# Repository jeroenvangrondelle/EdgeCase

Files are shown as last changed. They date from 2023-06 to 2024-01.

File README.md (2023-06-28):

# Edge Case: Housing your sensors at the edge

This work is licensed under a Creative Commons Attribution-ShareAlike 4.0 International License.

## Objective

Often when developing IoT use cases, sensors and supporting boards are readily available,
but housing the electronics at the edge is a challenge.

Would it be possible to develop an easily scalable, (semi) professional case design that bridges the gap between early prototyping
and high volume deployments?

## Current version

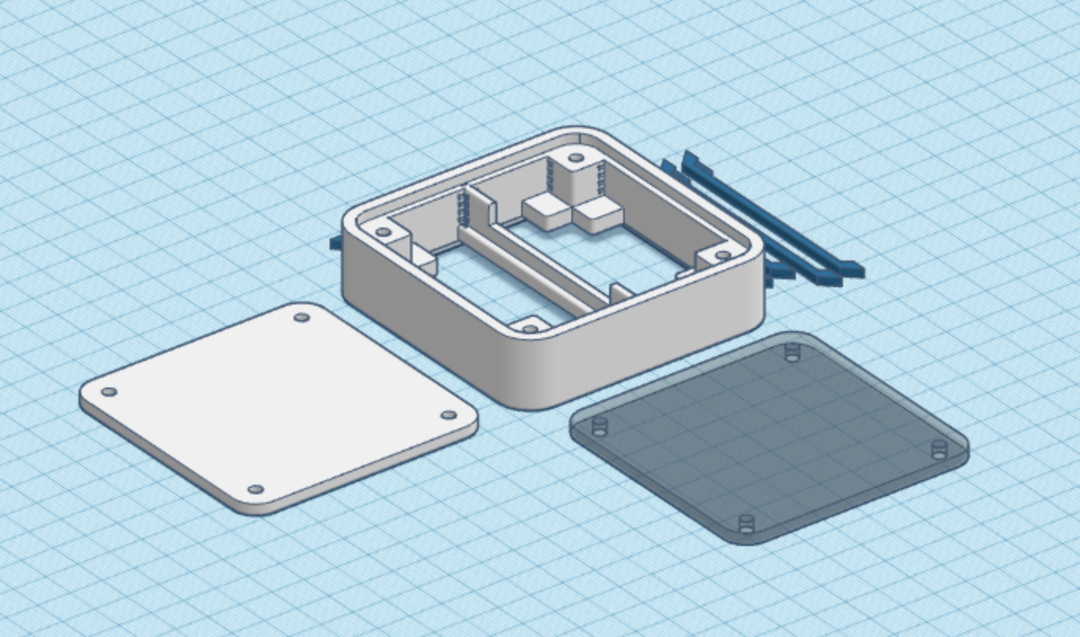
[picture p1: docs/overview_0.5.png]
Early prototype


## Features

- [ ] A base case-design with lasercut front and back and a 3D printed house
- [ ] A parametric implementation for automatic sizing to your specific PCB, battery holder, sensor, etc.
- [ ] Swappable back design: Table model, screw mounts, and DIN rail

## Scaling the case

Choose values for A, B, C and D so that your boards and/or battery holders fit, either vertically or horiontally, in the two slots.

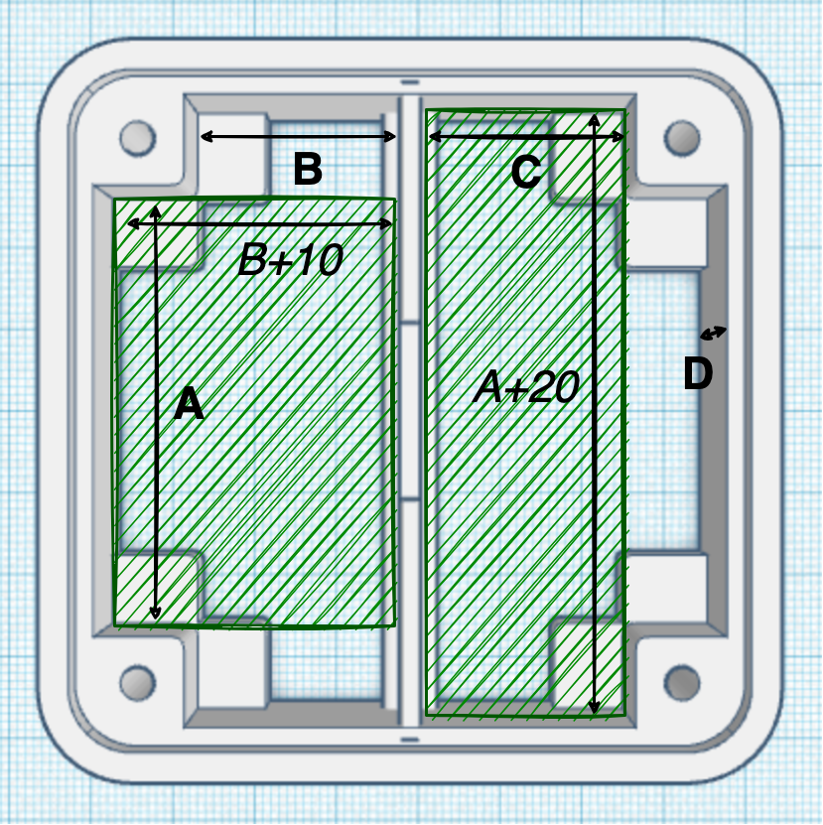
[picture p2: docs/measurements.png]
Measurements


## Roadmap for 1.0

- [ ] Connectors, (touch)buttons? 
- [ ] Status leds and ambient feedback?
- [ ] External sensor bay?
- [ ] How to parameterize the SVG's (better)?
- [ ] Online version of the design generator

## Version log

v0.2

- [X] Smoother/parallel circles
- [X] Better side thinknesses
- [X] Use screws for fixing front and back

v0.3 and v0.4

- [x] Smoother lines
- [x] Support horizontal and vertical placement
- [x] Parameterize towards PCB size + optional 2x 18650 battery holder

v0.5

- [x] Testing support for melt insert nuts (Ruthex M3 Schroefdraadbus M3 x 5.7)
- [x] Small irregularity in the design at top left corner of the case.
- [x] Fixing the boards with a clip
 
## Supported boards

| Board | A | B | C | D |
| ---|---|---|---|---|
| Firebeetle 2 (60x25.4mm, 62mm including protruding USB connector) + 18650 Battery Holder (80x21mm) | 62 mm | 16 mm | 21 mm | 30 mm |
| Arduino Nano (45x18mm) + 18650 Battery Holder (80x21mm) | 60 mm | 8 mm | 21 mm | 30 mm |

## Modding

Front and house are easy to mod. Front can be cut from plexiglas, but printing introduces extra modding options.

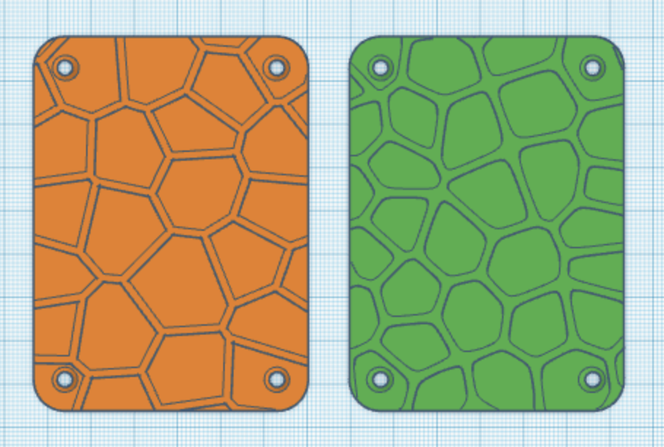
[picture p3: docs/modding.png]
Modding


## Contributors

Idea and design by Jeroen van Grondelle

With contributions and feedback from:

- Daan Boezeman
- ...

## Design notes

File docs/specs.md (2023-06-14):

In v0.2

Both bays have a size of 34x50.

Depth is 14

The board width = 47mm
- Split at 5 + 10 + slack
The bay width = 23
- Split at 5 + 47 + added + 3 + slack

The depth = 14
- Split at 10mm
The height = 50
- Split 1t 40

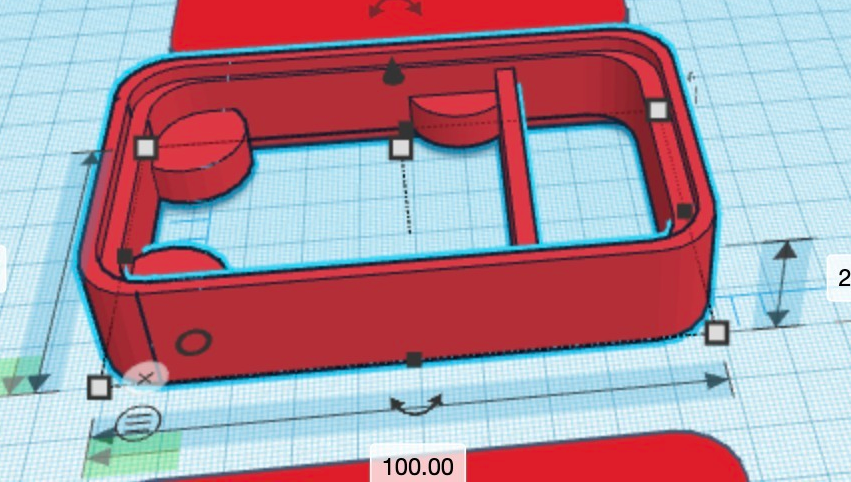
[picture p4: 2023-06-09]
docs/overview_0.1.png

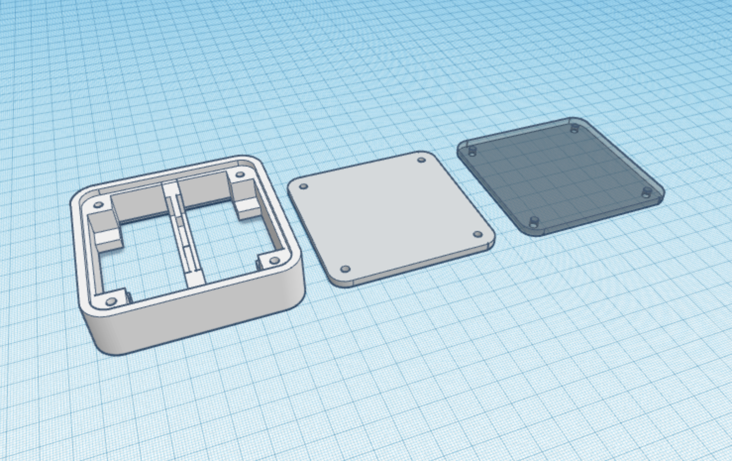
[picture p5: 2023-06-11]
docs/overview_0.2.png

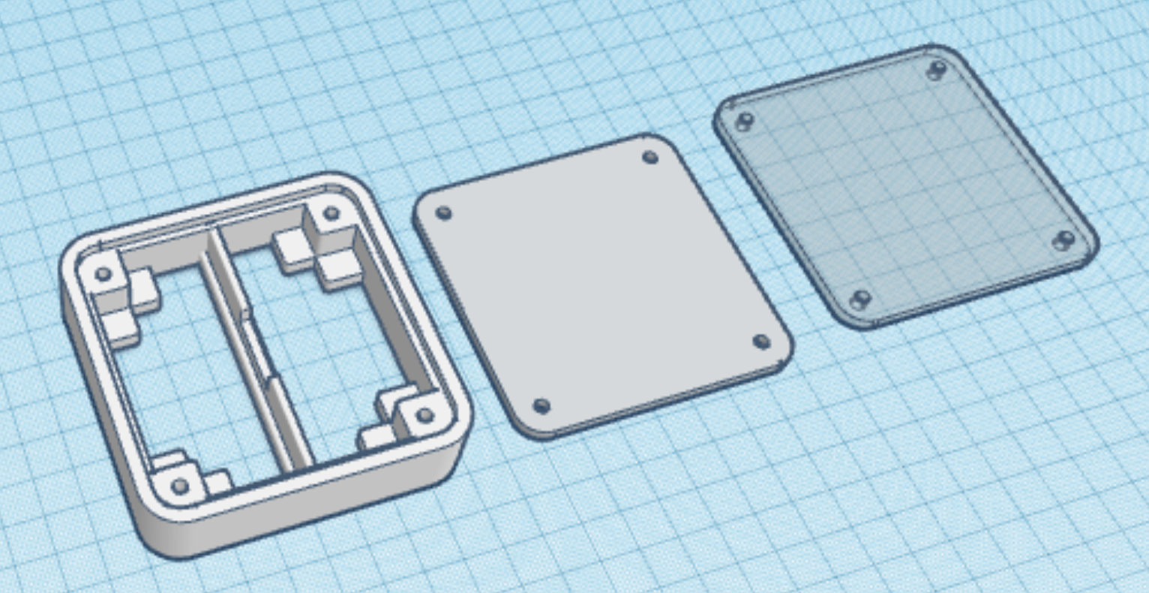
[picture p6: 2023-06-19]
docs/overview_0.4.png

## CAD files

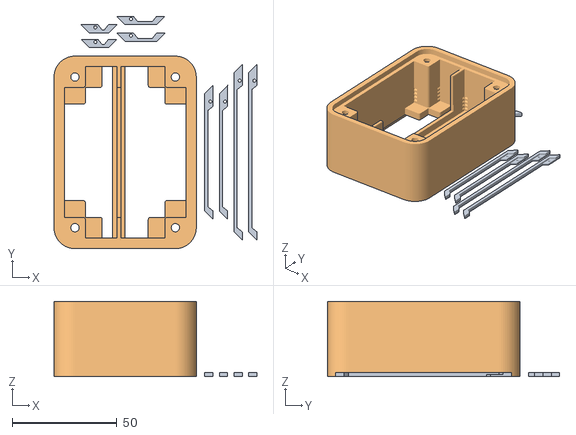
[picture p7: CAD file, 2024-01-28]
examples/liligo_18650_house.obj
97.0 x 111.0 x 36.0

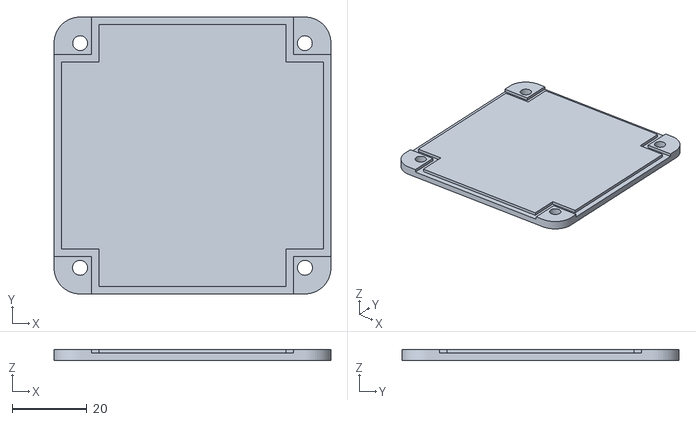
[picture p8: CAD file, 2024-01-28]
prototypes/Edge Case 0.6 WP.stl
74.0 x 74.0 x 3.00

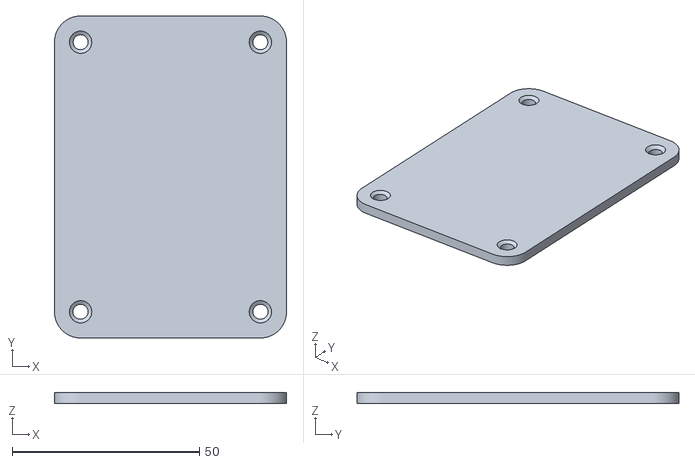
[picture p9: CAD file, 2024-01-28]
examples/liligo_18650_front.obj
62.0 x 86.0 x 3.00

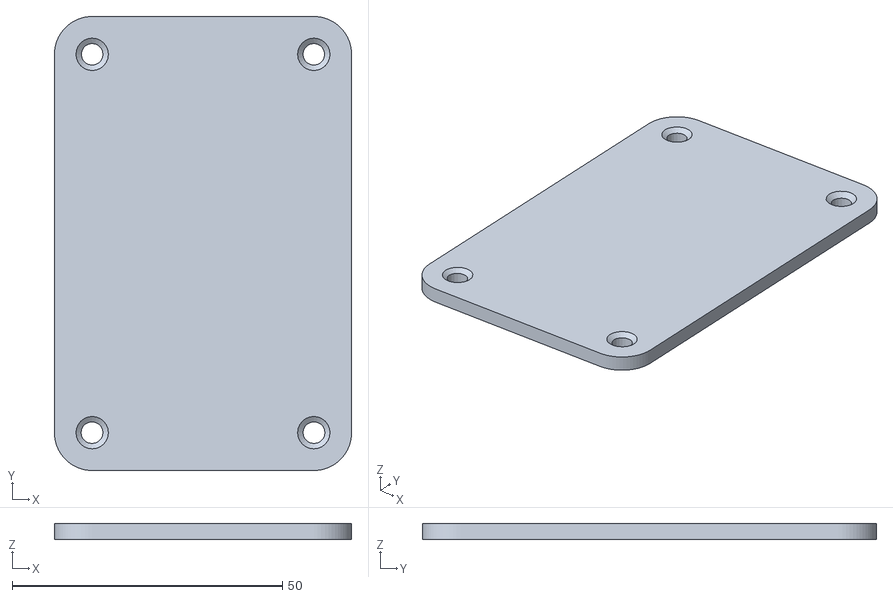
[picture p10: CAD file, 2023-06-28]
examples/nano_18650_front.obj
55.0 x 84.0 x 3.00

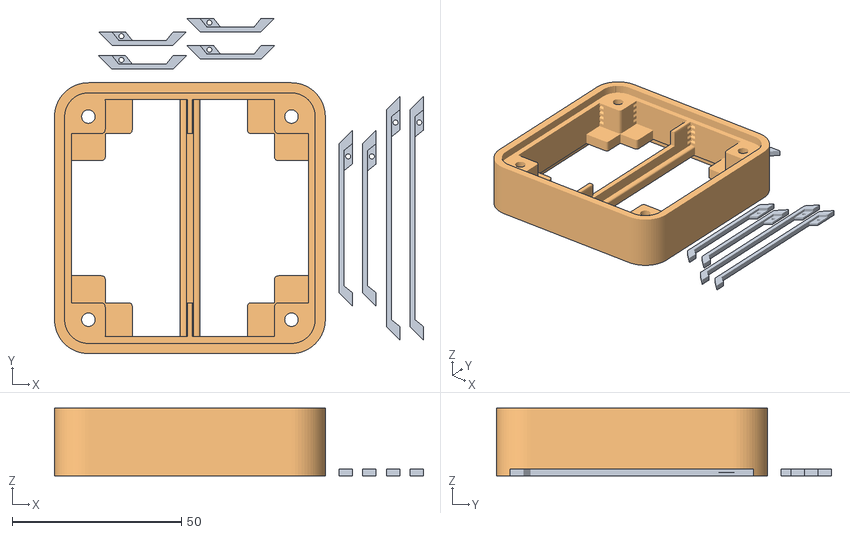
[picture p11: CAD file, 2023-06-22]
prototypes/Edge Case 0.5 House.obj
109.0 x 99.0 x 20.0

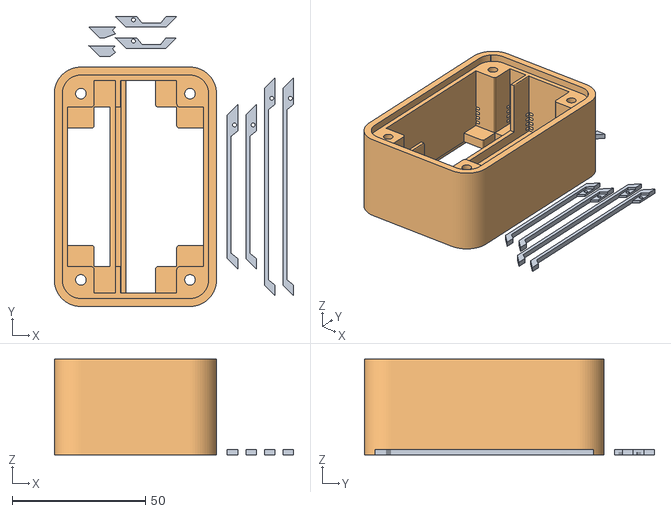
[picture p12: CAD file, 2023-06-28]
examples/nano_18650_house.obj
90.0 x 109.0 x 36.0

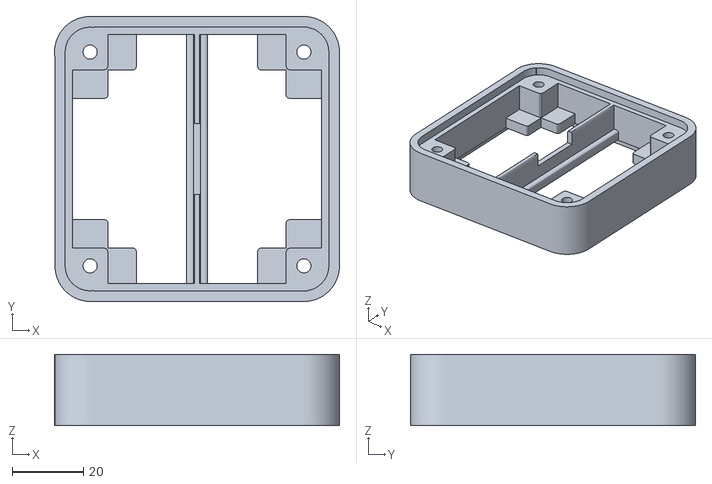
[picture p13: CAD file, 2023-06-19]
prototypes/Edge Case 0.4 House.obj
80.0 x 80.0 x 20.0

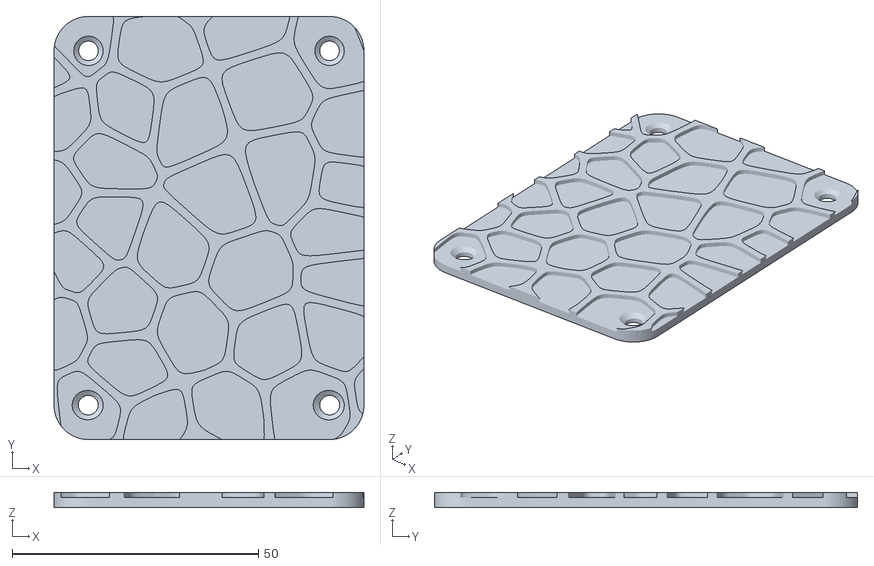
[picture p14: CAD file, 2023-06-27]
examples/single 18650_firebeetle2_front_voronoi.stl
63.0 x 86.0 x 3.00

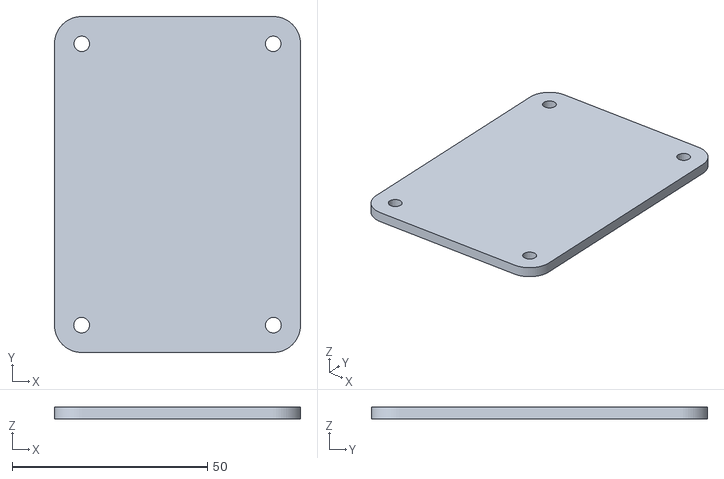
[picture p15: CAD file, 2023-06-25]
examples/single 18650_firebeetle2_front.obj
63.0 x 86.0 x 3.00

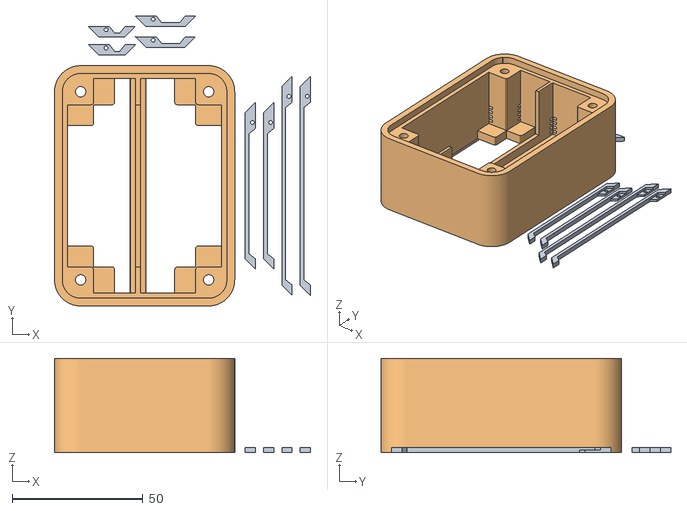
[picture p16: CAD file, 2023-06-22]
examples/single 18650_firebeetle2_house.obj
98.0 x 111.0 x 36.0

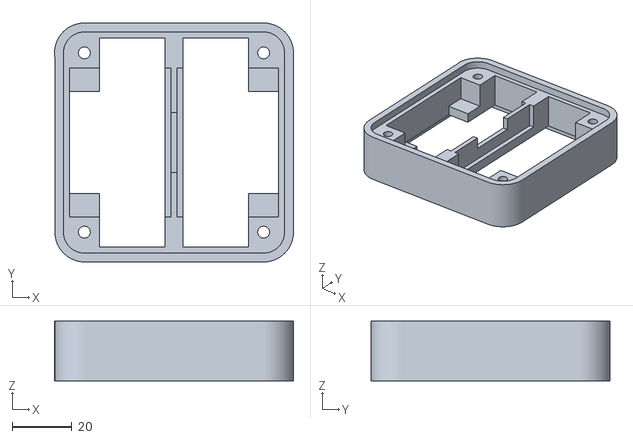
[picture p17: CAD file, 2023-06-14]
prototypes/Edge Case 0.2 House.obj
80.0 x 80.0 x 20.0

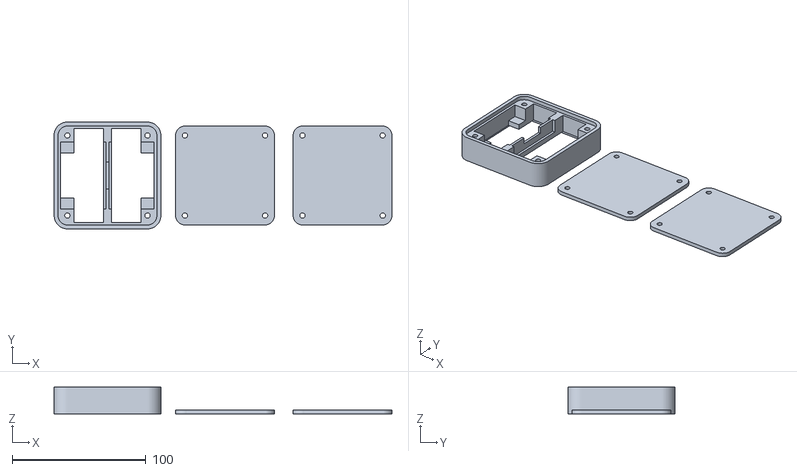
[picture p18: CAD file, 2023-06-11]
prototypes/Edge Case 0.2.stl
253.0 x 80.0 x 20.0

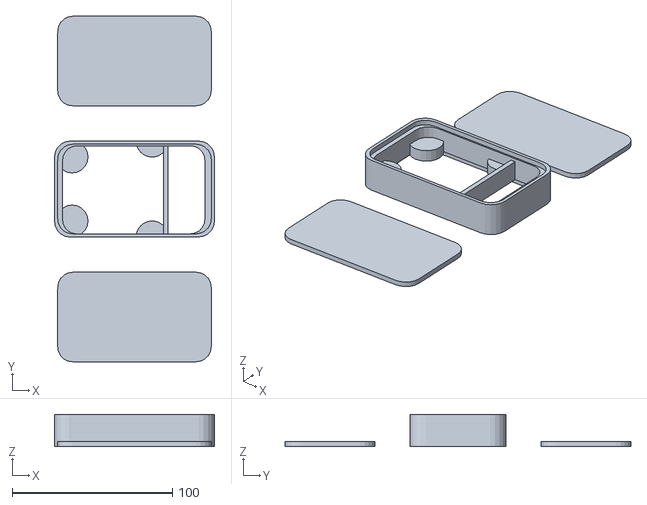
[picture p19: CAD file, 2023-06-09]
prototypes/Edge Case 0.1.stl
100.0 x 216.0 x 20.0

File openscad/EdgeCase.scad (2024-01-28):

/*

TODO

- [x] border height => 3mm
- [x] Check: lid fit
- [x] rounded studs
- [x] tapped screw holes
- [x] new type of rims instead of the 8 flaps?
- [x] slightly more curve in the seal?
- [] Make size actually changeable...
- [] Fix the lid spacing
- [] Make the edge (4)/lid (3) thickness independent of the case back thinckness (=2)
*/

include <BOSL2/std.scad>
include <BOSL2/wiring.scad>

// DEFAULTS, 8 by 8 box
//A=24;
//B=24;
//C=50;
//D=22;

//A=12;
//B=12;
//C=24;
//D=12;



A=16;
B=32;
C=70;
D=30;



has_back = true;
has_seal = true;
has_support = true;

wall=2;
edge=4;

width_y = A + B + 32; // 32 = 2* wand + stud + 2mm voor devider 
width_x = 62 + 30;
height = D + 2*edge;



detail = .2;
lid_gap = .1;

module wall()
{
    union() {
        up(0) rect_tube($fa = 4, $fs=detail, 
            size=[width_x, width_y], wall=wall, rounding=10, h=height);
        up(edge) rect_tube($fa = 4, $fs=detail, 
            size=[width_x-(2*wall),width_y-(2*wall)], wall=3, rounding=8, h=height-2*edge);
        
        up(edge + 1.5) right(width_x/2-6.5) cube([3, width_y-30, 3], center=true);
        up(edge + 1.5) right(-width_x/2+6.5) cube([3, width_y-30, 3], center=true);
        
        up(edge + 1.5) fwd(width_y/2-6.5) cube([width_x-30, 3, 3], center=true);
        up(edge + 1.5) fwd(-width_y/2+6.5) cube([width_x-30, 3, 3], center=true);
        
    }
}

module back() {
    up(edge/2) cuboid($fa = 4, $fs=detail, [width_x,width_y, edge],
        rounding=10, edges=[FWD+RIGHT,FWD+LEFT,BACK+LEFT, BACK+RIGHT]);
}

module lid() {
    difference() {
        cuboid($fa = 4, $fs=detail,[width_x-4-2*lid_gap, width_y-4-2*lid_gap, edge-1], 
            rounding=8-lid_gap, edges=[FWD+RIGHT,FWD+LEFT,BACK+LEFT, BACK+RIGHT]);
        union() {
            
            //holes
            translate([width_x/2-9,width_y/2-9,0]) {
                cylinder($fa = 4, $fs=0.1, h=30, r=2, center=true);
                up(edge-3) zcyl($fa = 4, $fs=detail, h=1.5, r1=2, r2=4);
            }
            translate([-(width_x/2-9),width_y/2-9,0])
            {
                cylinder($fa = 4, $fs=0.1, h=30, r=2, center=true);
                up(edge-3) zcyl($fa = 4, $fs=detail, l=1.5, r1=2, r2=4);
            }
            translate([width_x/2-9,-(width_y/2-9),0]) {
                cylinder($fa = 4, $fs=0.1, h=30, r=2, center=true);
               up(edge-3) zcyl($fa = 4, $fs=detail, l=1.5, r1=2, r2=4);
            }
            translate([-(width_x/2-9),-(width_y/2-9),0]) {
                cylinder($fa = 4, $fs=0.1, h=30, r=2, center=true);
                up(edge-3) zcyl($fa = 4, $fs=detail, l=1.5, r1=2, r2=4);
            }
        }
    }
}

module stud() {
    union() {
        difference() {
            translate([-5,-5, edge])
            {   
                diff()
                    cube([10, 10, height-2*edge], center=false)
                        edge_mask(BACK+RIGHT) 
                            #rounding_edge_mask(l=height-2*edge, r=4, orient=UP);
            }    
            translate([-1,-1,0]) cylinder($fa = 4, $fs=detail, h=height, r=2);
        }
    }
}

module support()
{
    opening_width = 0.5 * (width_x-10);
    translate([-(width_x-10)/2, -3, edge]) cube([width_x-10,6,3]);
    difference() {
        translate([-(width_x-10)/2, -1, edge+3]) cube([width_x-10, 2, D-3]);
        translate([-opening_width/2, -1.5, 9]) cube([opening_width, 3, 33]);
    }
}

module house() {
    seal_x = width_x/2 - 3;
    seal_y = width_y/2 - 3;
    
    difference() {
        union() { 
            if (has_back) { back(); }
            
            wall();
            
            // four studs
            
            translate([-(width_x-20)/2,-(width_y-20)/2,0]) stud();
            translate([-(width_x-20)/2,(width_y-20)/2,0]) rotate(-90) stud();
            translate([(width_x-20)/2,-(width_y-20)/2,0]) rotate(90) stud();
            translate([(width_x-20)/2,(width_y-20)/2,0])  rotate(180) stud();
            
            if (has_support) { support(); }
            
        }
        union() {
            //cube([100,100,40], center=true);
           
            // back seal, if no back
            if(!has_back && has_seal) {
                up(edge+0.4) wire_bundle($fa = 4, $fs=detail, [
                    [-seal_x,       0, 0], 
                    [-seal_x,       -seal_y+10, 0], 
                    [-seal_x+10,    -seal_y+10, 0], 
                    [-seal_x+10,    -seal_y, 0], 
                    [seal_x-10,     -seal_y, 0], 
                    [seal_x-10,     -seal_y+10, 0], 
                    [seal_x,        -seal_y+10,    0], 
                    [seal_x,        seal_y-10,    0], 
                    [seal_x-10,     seal_y-10, 0], 
                    [seal_x-10,     seal_y, 0], 
                    [-seal_x+10,    seal_y, 0], 
                    [-seal_x+10,    seal_y-10, 0], 
                    [-seal_x,       seal_y-10,   0], 
                    [-seal_x, .01,  0]], 
                    rounding=3, wirediam=2, wires=1);
            }
            // front seal
            if(has_seal) {
               //was 26.62
                up(D + edge - 0.4) wire_bundle($fa = 4, $fs=detail, [
                    [-seal_x,       0, 0], 
                    [-seal_x,       -seal_y+10, 0], 
                    [-seal_x+10,    -seal_y+10, 0], 
                    [-seal_x+10,    -seal_y, 0], 
                    [seal_x-10,     -seal_y, 0], 
                    [seal_x-10,     -seal_y+10, 0], 
                    [seal_x,        -seal_y+10,    0], 
                    [seal_x,        seal_y-10,    0], 
                    [seal_x-10,     seal_y-10, 0], 
                    [seal_x-10,     seal_y, 0], 
                    [-seal_x+10,    seal_y, 0], 
                    [-seal_x+10,    seal_y-10, 0], 
                    [-seal_x,       seal_y-10,   0], 
                    [-seal_x, .01,  0]], 
                    rounding=3, wirediam=2, wires=1);
            }
        }
    }
}

house();

right(100) lid();

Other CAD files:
prototypes/Edge Case 0.5 Front.obj
prototypes/Edge Case 0.3 House.obj
prototypes/Edge Case 0.2 Front.obj
prototypes/Edge Case 0.1.obj
prototypes/Edge Case 0.2.obj
prototypes/Edge Case 0.6 WP.obj

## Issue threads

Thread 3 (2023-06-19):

Keuzen rond schroeven

jeroenvangrondelle, 2023-06-19:
HEX spacers inserted into screw holes, small screws from both ends
https://nl.aliexpress.com/item/1005003749472330.html
https://nl.aliexpress.com/item/1005004339503007.html

Use patent bolds from one end.
https://nl.aliexpress.com/item/1005004190312079.html

Koperen inzetmoeren, met lijm/of heet erin duwen
https://nl.aliexpress.com/item/1005003718510194.html
https://www.amazon.nl/ruthex-Schroefdraadbus-schroefdraadbussen-Insteekmoer-3D-geprinte/dp/B08BCRZZS3/

jeroenvangrondelle, 2023-06-22:
We went with the inzetmoeren

Closed 2023-06-22.

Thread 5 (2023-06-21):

There is a flaw in the top left side of the case.

jeroenvangrondelle, 2023-06-21:

jeroenvangrondelle, 2023-06-22:
Fixed in 0.5

Closed 2023-06-22.

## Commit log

2023-06-09 First first drafts
    [Edge Case 0.1.stl]
2023-06-11 Version 0.2
    [Edge Case 0.1.obj, Edge Case 0.2.obj, Edge Case 0.2.stl]
2023-06-11 First code to transform the case to specific sizes
2023-06-11 Completed the separator
    [Edge Case 0.2.obj, Edge Case 0.2.stl]
2023-06-14 Tweaking generator
    [Edge Case 0.2 Front.obj, Edge Case 0.2 House.obj]
2023-06-19 V0.4, Better scaling, Extra docs
    [Edge Case 0.3 House.obj, Edge Case 0.4 House.obj, dual18650.obj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]
2023-06-19 Generate based on 0.4, and other fixes
    [Edge Case 0.4 House.obj]
2023-06-21 Fixed some sizing issues based on actual use.
    [single 18650_firebeetle2.obj]
2023-06-21 Fixed a small cosmetic error in the curve of the case
    [Edge Case 0.5 House.obj]
2023-06-21 Example case based on the new design (+small fix in the build script)
    [single 18650_firebeetle2.obj]
2023-06-21 Curve problem in case was visible in image
2023-06-21 Slightly higher case for the example case
    [single 18650_firebeetle2.obj]
2023-06-22 Some updates to 0.5
    [Edge Case 0.5 House.obj, single 18650_firebeetle2.obj]
2023-06-22 Fix one missing clip
    [Edge Case 0.5 House.obj, single 18650_firebeetle2.obj]
2023-06-22 Tested one melt insert, looks great!
2023-06-25 Fronts can be cut, but also printed.
    [Edge Case 0.5 Front.obj]
2023-06-25 Updates for printing front
    [single 18650_firebeetle2_front.obj, single 18650_firebeetle2_house.obj]
2023-06-27 Aanpassing getapte schroefgaten, fijnmaziger voronoi
    [Edge Case 0.5 Front.obj, single 18650_firebeetle2_front_voronoi.stl]
2023-06-28 Added example files for Arduino nano board
    [dual18650.obj, nano_18650_front.obj, nano_18650_house.obj]
2023-07-06 Experiment to produce EdgeCase in OpenScad, inc first attempt at rubber O-ring.
    [EdgeCase.scad]
2023-07-08 OpenScad version: - Parameters - Waterproof - lid
    [EdgeCase.scad]
2023-07-08 Sunk screws in lid, 3mm border
    [EdgeCase.scad]
2023-07-10 Overall improvements: Moved holes, better seal, fixed back
    [EdgeCase.scad]
2024-01-28 Diverse improvements
    [Edge Case 0.6 WP.obj, Edge Case 0.6 WP.stl, EdgeCase.scad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]
